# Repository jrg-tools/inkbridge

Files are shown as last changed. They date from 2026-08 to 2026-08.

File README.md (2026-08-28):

# inkbridge

A minimal, always-on **Home Assistant script launcher** on an e-ink display. Two mechanical buttons, sub-second feedback, runs for ages on almost no power.

```
┌──────────────────────────────┐
│                           (》)│
│                                │
│   ┌────────┐    ┌────────┐   │
│   │  bulb  │    │  wifi  │   │
│   │ Sleep  │    │Transfer│   │
│   └────────┘    └────────┘   │
│                                │
│ ──────────────────────────── │
│  A                      ▲ ▼  │
│                    "Sleep"    │
└──────────────────────────────┘
```

- A 2-column grid of icon-only buttons — each one a script configured in Home Assistant (lights, scenes, "goodnight" routines, whatever you script). Press it, it runs, done.
- Configure everything — WiFi networks (with automatic fallback), Home Assistant host/token, the script buttons and their icons, hotspot credentials, language, even the device's font — from a web UI the device serves itself.
- Multiple saved WiFi networks: tried in priority order until one connects, so it isn't stuck if you move it between locations.
- Idle **light sleep** after 5 minutes on any screen except while the config web UI is being used, waking instantly on either button. The header shows a small status icon (moon = about to nap, lightning = USB connected) that stays in sync even without touching a button.

Architecture follows [CrossPoint Reader](https://github.com/crosspoint-reader/crosspoint-reader): HAL singletons, an Android-style Activity stack for screens, a persisted settings singleton, an API-first web server, and — for the icon set — the same idea of rasterizing stock [Lucide](https://lucide.dev) icons to 1-bit bitmaps rather than hand-drawing vector shapes.

## Hardware

| Part | Details |
|---|---|
| MCU | Seeed Studio XIAO ESP32-S3 |
| Display | Waveshare 2.13" e-Paper HAT V4 (250x122, SPI) |
| Input | 2x Cherry MX switches (A/B) |
| Power | USB-C, EEMB 603449 LiPo (3.7V, 1100mAh) |

### Wiring

| HAT pin | XIAO pin | GPIO | Purpose |
|---|---|---:|---|
| VCC | 3V3 | — | Power |
| GND | GND | — | Ground |
| DIN | D10 | 9 | SPI MOSI |
| CLK | D8 | 7 | SPI clock |
| CS | D1 | 2 | Chip select |
| DC | D2 | 3 | Data/Command |
| RST | D3 | 4 | Reset |
| BUSY | D4 | 5 | Busy status |
| Button A | D6 | 43 | to GND (internal pull-up) |
| Button B | D7 | 44 | to GND (internal pull-up) |

### Power

- **Idle light sleep**: after 5 minutes untouched, the device drops into light sleep (`esp_light_sleep_start`) and wakes instantly on either button press. Skipped while the config web server is running (AP setup or a connected WiFi session), so it never naps mid-configuration.
- **No deep sleep**: true deep sleep wakeup (`ext0`/`ext1`) needs RTC-capable GPIOs (0–21 on the S3); the buttons are wired to GPIO43/44 (the UART pins), which aren't RTC pins. Light sleep's GPIO wakeup works on any digital pin instead, and has the added benefit of preserving all RAM state across the nap.
- **Rough battery life**: active draw is tens of mA; light sleep drops that to roughly 0.25–1 mA. At typical "check it a dozen-ish times a day" usage, that's on the order of 2–3 weeks per charge; left almost untouched, more like a month or two. Frequent short interactions cost more than you'd expect, since each one keeps it awake for the full 5-minute idle window afterward, not just the interaction itself.
- **Charging**: the XIAO's onboard charge management fast-charges at a fixed 100mA regardless of what the USB-C source can supply. For the 1100mAh cell here, that's roughly **11–14 hours** empty to full.
- No software-readable charging-status or battery-voltage pin exists on stock XIAO ESP32-S3 wiring — the header's lightning-bolt icon reflects "USB host connected" (native-USB frame detection), not literal charge state, and won't fire for a dumb USB-C power brick with no data lines.

## Using the device

Boot goes straight to the main menu — no radio starts until you pick something:

- **Script buttons**: each one configured in the web UI (label, HA script ID, icon) shows up as an icon-only square. Pressing it joins WiFi (trying each saved network in order), calls `script.turn_on` for that script's entity, and returns to the menu — a spinner is the only feedback while it works, and the footer shows its name while it's selected.
- **Transfer**: opens WiFi/hotspot connectivity —
  - *Setup hotspot* opens the access point `inkbridge-setup`. Join it, then open `http://inkbridge.local` (or `http://192.168.4.1`) to configure WiFi networks, Home Assistant host/token, scripts, hotspot, language, and font. Saving restarts the device.
  - *Connect WiFi* joins a saved network (again trying each until one connects) and starts the same config web server on your LAN — the screen then shows a QR code plus the mDNS name and IP to reach it from a browser. It does nothing else; no on-device entity control.

Button language (everywhere):

| Gesture | Action |
|---|---|
| A short | next row (wraps) |
| A long | previous row (wraps) |
| B short | select / run |
| B long | back |

The footer always shows a bold **A** (bottom-left, the action button) and up/down chevrons (bottom-right, the move button); on the main menu it also centers the currently selected item's name.

## Repository layout

```
lib/hal/                    Hardware abstraction (reusable, app-agnostic)
  HalDisplay                  GxEPD2 wrapper; FULL/FAST/region refresh, ghosting cadence
  HalGPIO                      Debounced buttons, short/long-press events, sleep-wakeup arming
scripts/
  gen_icons.py                 Rasterizes stock Lucide SVGs into 1-bit icon bitmaps
src/
  main.cpp                     Globals + setup()/loop(); idle-sleep + header status-icon polling
  InkBridgeSettings             Persisted settings singleton (NVS), SETTINGS macro
  Version.h                     Firmware version string
  IdleSleep.h                   Shared idle-timeout/warning-window constants and clock
  activities/                   One screen = one Activity
    Activity, ActivityManager     Lifecycle + deferred screen stack
    UiListActivity                 Reusable scrolling-list base
    menu/                           MainMenuActivity — the 2-column script/Transfer grid
    transfer/ network/ scripts/     Transfer menu, WiFi/hotspot screens, script-run screen
  components/                   UITheme (fonts/metrics), Icons + icons/IconBitmaps.h,
                                  UiChrome (header/footer/rows), QrCode (QR rendering)
  homeassistant/                 HA REST client — runs a script via script.turn_on
  network/                       ConfigWebServer (JSON API + static SvelteKit UI),
                                  WifiConnector (multi-network fallback)
  i18n/                          I18n singleton + EN/ES string table
web/                          SvelteKit config UI (TypeScript, pnpm, adapter-static, @lucide/svelte icon picker)
nix/                          Dev environment (flake)
data/                         Staged web build, flashed to LittleFS (generated)
```

## Development

### Environment

Everything is provided by the Nix dev shell (PlatformIO, Node 24, pnpm, clang-format):

```sh
nix develop ./nix
```

First entry bootstraps a `.venv` with PlatformIO Core automatically. Works on Linux (FHS env) and macOS. Without Nix you need: PlatformIO Core, Node.js >= 24, pnpm.

### Quick commands (inside the shell)

| Command | What it does |
|---|---|
| `build-ui` | Build the SvelteKit UI and stage it into `data/` |
| `flash-ui` | `build-ui` + flash the LittleFS partition |
| `flash` | Flash the firmware |
| `flash-monitor` | Flash the firmware + attach the serial monitor |
| `flash-all` | UI + filesystem + firmware + monitor (full deploy) |

First flash on a new board: `flash-all`. Day-to-day firmware work: `flash-monitor`. UI-only change: `flash-ui`.

### Working on the web UI

```sh
cd web
pnpm dev
```

`/api/*` calls are proxied to a real device — defaults to `inkbridge.local`, override with `INKBRIDGE_HOST=192.168.4.1 pnpm dev`. Put the device in Setup mode (or on your LAN) so the API is reachable.

`pnpm check` type-checks the app; `pnpm build` produces the static site; `pnpm deploy` does both and stages the result into `../data` (equivalent to the `build-ui` shell command above).

### Regenerating icons

Device icons are real [Lucide](https://lucide.dev) glyphs rasterized to 1-bit bitmaps (`src/components/icons/IconBitmaps.h`) — no hand-drawn vector shapes, no SVG rendering on-device. To add or change one, edit the `ICONS` list in `scripts/gen_icons.py` (path/circle/rect data, easiest lifted from `@lucide/svelte`'s source under `web/node_modules`) and rerun:

```sh
python3 scripts/gen_icons.py
```

Requires ImageMagick (`magick`) on `PATH` for SVG rasterization. Writes straight back into `src/components/icons/IconBitmaps.h` — don't hand-edit that file. If the icon is meant to be selectable from a script button, also add it to `ICON_OPTIONS` in `web/src/routes/+page.svelte` and to `Icons::byKey()` in `src/components/Icons.h`.

### Web API

The device is API-first; the UI is a static SvelteKit build served from LittleFS. CORS is enabled.

| Endpoint | Method | Description |
|---|---|---|
| `/api/status` | GET | `{version, ip, mode, rssi, freeHeap, uptime}` |
| `/api/settings` | GET | Current settings (secrets omitted; WiFi networks return SSID only) |
| `/api/settings` | POST | JSON body; applies + persists. Secrets/passwords only overwritten when present — matched by SSID for WiFi networks, so leaving a password blank keeps the stored one |
| `/api/restart` | POST | Reboot the device |

Settings are grouped as `transfer` (`wifiNetworks: [{ssid, password}]`, `haHost`, `haPort`, `haToken`, `haScripts: [{label, id, icon}]`) and `settings` (`language`, `fontFamily`, `apSsid`, `apPassword`).

### Conventions

- C++20, no exceptions in app code, 2-space indent, 120 columns
- `PascalCase` classes (one per file), `camelCase` methods/members, `UPPER_SNAKE_CASE` constants
- `lib/` is hardware-agnostic/reusable; `src/` is app logic
- Screens are Activities: implement `onEnter/onExit/loop/render`, request repaints with `requestUpdate()`; never transition mid-`loop()` — ask `activityManager`
- e-ink discipline: FAST (partial) refresh by default, full refresh every 15 frames to clear ghosting; use `refreshRegion()` when only a small area changed

## Roadmap

- [x] M0 — display, buttons, menu
- [x] M1 — WiFi (multi-network fallback) + Home Assistant
- [x] M2 — script launcher + web config + idle sleep
- [ ] M3 — shopping list (microSD)
- [ ] M4 — OTA updates

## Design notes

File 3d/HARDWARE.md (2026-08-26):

# Filament

| Characteristic | Specification |
|---|---|
| **Material** | PLA |
| **Color** | White |
| **Diameter** | 1.75 mm |
| **Diameter tolerance** | ±0.02 mm |
| **Net weight** | 1 kg / 2.2 lb |
| **Density** | 1.20 g/cm³ |
| **Tensile strength (X-Y)** | ≥ 50 MPa |
| **Elongation at break** | 11.2% |
| **Bending strength** | 91 MPa |
| **Bending modulus** | 1913 MPa |
| **Impact strength** | 5.4 kJ/m² |
| **Heat deflection temperature** | 53°C @ 0.45 MPa |
| **Rockwell hardness** | 88 |
| **Nozzle temperature** | 190–230°C |
| **Recommended nozzle temperature** | ~205°C |
| **Bed temperature** | 50–65°C |
| **Recommended print speed** | 30–70 mm/s |
| **Part cooling fan** | 100% |
| **Drying temperature** | 55 ± 5°C |
| **Storage humidity** | ≤20% RH |
| **Filament length** | ~330–335 m/kg |

## Bambu A1 Starting Profile

- **Filament type:** Generic PLA
- **Nozzle:** 205°C
- **Bed:** 55–60°C
- **Part cooling:** 100%
- **Print speed:** 30–70 mm/s for conservative printing
- **Drying:** 55°C for ~6 h if moisture is suspected

## Notes

- The **±0.02 mm** specification refers to filament diameter tolerance, not printed-part dimensional accuracy.
- Compatible with standard **1.75 mm FDM/FFF 3D printers**.
- Suitable for general-purpose PLA printing.

# Components

## EEMB 3.7V 1100mAh LiPo Battery — 603449

| Characteristic | Specification |
| --- | --- |
| **Manufacturer** | EEMB |
| **Battery type** | Lithium-Polymer (LiPo) |
| **Nominal voltage** | 3.7 V |
| **Capacity** | 1100 mAh |
| **Energy** | ~4.07 Wh |
| **Model / Size** | 603449 |
| **Dimensions** | 34.5 × 51 × 6.3 mm |
| **Connector** | JST-PHR-02 |
| **Connector pitch** | 2.0 mm |
| **Wires** | Red (+) / Black (−) |
| **Protection** | Built-in PCM |
| **Protection features** | Overcharge, over-discharge, over-current, short circuit |
| **Cycle life** | >500 cycles |
| **Certifications** | UL, IEC 62133-2 |
| **Transportation** | UN38.3 compliant |
| **Recommended storage charge** | 40–60% |
| **Storage voltage** | 3.7–4.0 V |
| **Recommended recharge interval** | Every 3 months |
| **Maximum recommended storage temperature** | <25°C |
| **Recommended storage conditions** | Cool and dry place |

## 2.13" SPI E-Ink / E-Paper Display HAT

| Characteristic | Specification |
| --- | --- |
| **Display type** | Electronic Paper / E-Ink |
| **Display size** | 2.13" |
| **Display area** | 23.71 × 48.55 mm |
| **Resolution** | 250 × 122 pixels |
| **Aspect ratio** | ~2.05:1 |
| **Pixel / dot pitch** | 0.194 × 0.194 mm |
| **Shown colors** | Black & White |
| **Gray levels** | 2 |
| **Interface** | SPI |
| **Operating voltage** | 3.3 V / 5 V |
| **Partial refresh time** | ~0.3 s |
| **Full refresh time** | ~2 s |
| **Refresh power** | ~26.4 mW (typ.) |
| **Standby power** | <0.017 mW |
| **Viewing angle** | >170° |
| **Module dimensions** | ~65 × 30 mm |
| **Compatible platforms** | Raspberry Pi, Arduino and other SPI-compatible MCUs |

## Seeed Studio XIAO ESP32-S3 Sense — Without Camera

| Characteristic | Specification |
| --- | --- |
| **MCU** | ESP32-S3 |
| **CPU architecture** | 32-bit Xtensa |
| **CPU cores** | Dual-core |
| **Maximum frequency** | 240 MHz |
| **Wi-Fi** | 2.4 GHz |
| **Bluetooth** | BLE 5.0 |
| **PSRAM** | 8 MB |
| **Flash** | 8 MB |
| **Digital microphone** | Yes |
| **Camera** | **Removed / not used** |
| **SD card support** | Yes |
| **Maximum SD card capacity** | 32 GB |
| **SD card filesystem** | FAT |
| **Battery charging** | Yes |
| **Antenna connector** | U.FL |
| **Wireless range** | >100 m with external U.FL antenna (manufacturer claim) |
| **Board dimensions** | 21 × 17.5 mm |
| **Development platforms** | Arduino, MicroPython |
| **Form factor** | Seeed Studio XIAO |

## Cherry MX2A Silent Blue — Mechanical Keyboard Switch

| Characteristic | Specification |
| --- | --- |
| **Brand** | 遊舎工房 |
| **Manufacturer** | 遊舎工房 |
| **Switch model** | Cherry MX2A Silent Blue |
| **Switch type** | Tactile |
| **Color / Axis** | Blue |
| **Actuation type** | Clicky |
| **Pins** | 5-pin |
| **Compatibility** | Cherry MX |
| **Total travel** | 4.0 mm |
| **Working / actuation travel** | 2.2 mm |
| **Operating force** | 50 cN |
| **Package quantity** | 35 switches |
| **Package dimensions** | 14.4 × 10.6 × 2.4 cm |
| **Package weight** | 100 g |
| **Factory lubrication** | No |

## YMDK Kailh Hot-Swappable PCB Socket — CPG151101S11

| Characteristic | Specification |
| --- | --- |
| **Brand** | YMDK / Kailh |
| **Model** | CPG151101S11 |
| **Component type** | Mechanical keyboard hot-swap socket  |
| **Package quantity** | 50 sockets |
| **Rated voltage** | 12 V AC/DC max |
| **Minimum rated voltage** | 2 V AC min |
| **Rated current** | 10 mA AC/DC max |
| **Minimum rated current** | 10 μA DC |
| **Contact resistance** | ≤200 mΩ |
| **Insulation resistance** | ≥100 mΩ @ 100 V DC |
| **Withstanding voltage** | AC 100 V, 50–60 Hz |
| **Insertion / motivational force** | ≤6.6 lbf / 3.0 kgf |
| **Operating life** | 100 cycles |
| **Switch compatibility** | Kailh / MX-style mechanical switches |
| **Application** | Mechanical keyboard / keypad / HMI |

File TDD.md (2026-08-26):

# TDD — eink-remote: Home Assistant Controller on ESP32-S3

## 1. Overview

**eink-remote** is a minimal, self-contained Home Assistant remote controller built on an ESP32-S3 with a 2.13" e-ink display, 2 mechanical buttons, microSD storage, and a microphone for voice input.

The device acts as a **local physical interface** to Home Assistant:
- Control lights, switches, and other entities
- Display live state from Home Assistant
- Maintain a shopping list
- Receive firmware updates over-the-air
- Configure settings via a local web server

It is **not** a general-purpose IoT platform. It solves one problem very well: being a fast, low-power, always-available physical remote control.

---

## 2. Hardware

**MCU:** Seeed Studio XIAO ESP32-S3
- 14 GPIO pins total
- Wi-Fi + BLE capable
- USB-C power/programming

**Display:** Waveshare 2.13" e-Paper HAT V4
- 250x122 pixel resolution
- SPI interface (6 GPIO pins)
- Low power (only draws current during refresh)

**Input:** 2x Cherry MX mechanical switches (hotswap PCB)
- GPIO interrupt-based (2 GPIO pins)
- Physical feedback (important for UX)
- Debounced in hardware (20ms)
- Short-press / long-press / double-press patterns to compensate for fewer keys

**Storage:** microSD card (SPI mode)
- Shares SPI bus with display (separate CS pin → 1 extra GPIO)
- Stores shopping list, logs, audio clips, config backups

**Microphone:** The XIAO ESP32-S3 (base version) has **no** built-in mic
- The XIAO ESP32-S3 **Sense** variant includes a PDM digital microphone + microSD slot (recommended — solves both needs with zero wiring)
- Otherwise: external I2S MEMS mic (e.g. INMP441/SPH0645, 3 GPIO pins)

**Power:** USB-C (for now; future: battery + low-power deep sleep)

#### Pin Connection

| # | HAT pin (silkscreen order) | Wire color (typical Waveshare cable) | XIAO label | XIAO GPIO | Purpose |
| - | --- | --- | --- | ---: | --- |
| 1 | VCC | grey/red | `3V3` | — | Power (3.3 V) |
| 2 | GND | brown/black | `GND` | — | Ground |
| 3 | DIN | blue | `D10` | 9 | SPI MOSI (data in) |
| 4 | CLK | yellow | `D8` | 7 | SPI clock |
| 5 | CS | orange | `D1` | 2 | Chip select |
| 6 | DC | green | `D2` | 3 | Data/Command |
| 7 | RST | white | `D3` | 4 | Reset |
| 8 | BUSY | purple | `D4` | 5 | Busy status |

---

## 3. Goals

### Primary

1. Build a working Home Assistant remote controller
2. Display live HA entity state on e-ink
3. Control HA lights/switches via 2 physical buttons
4. Navigate between remote, dashboard, and shopping list screens
5. Persist configuration (Wi-Fi, HA host, token) across reboot
6. Support Over-The-Air firmware updates
7. Make the UI responsive (button press → display update in <1 second)
8. Run on minimal power (e-ink refresh only when state changes)

### Secondary

- Sync shopping list with HA (optional YAML helper)
- BLE presence detection (future)
- Battery + deep sleep (future)
- Scheduled automations (future)

---

## 4. Non-Goals

- **Not** a general IoT platform (unlike the original TDD)
- **Not** replacing Home Assistant (HA remains the brain)
- **Not** building an e-reader
- **Not** supporting complex automations on-device
- **Not** providing a full dashboard (limited display size)
- **Not** cloud connectivity (local network only)

---

## 5. High-Level Architecture

```mermaid
graph TB
    HA[Home Assistant<br/>on local network]
    
    WiFi[Wi-Fi]
    
    subgraph "eink-remote"
        App["Application<br/>Event Loop"]
        Display["Display<br/>Renderer"]
        Buttons["Button<br/>Handler"]
        Storage["Storage<br/>NVS + microSD"]
        HAClient["HA Client<br/>REST/WebSocket"]
        Web["Web Config<br/>Server"]
        ShoppingList["Shopping List<br/>Manager"]
    end
    
    Disp["e-Ink Display<br/>2.13in"]
    Btn["2x Cherry MX<br/>Switches"]
    Mic["Microphone<br/>PDM/I2S"]
    SD["microSD Card<br/>SPI"]
    
    HA -->|REST/WS| WiFi
    WiFi -->|Wi-Fi| HAClient
    
    Buttons -->|Button events| App
    HAClient -->|State updates| App
    App -->|Render command| Display
    Display -->|Pixel data| Disp
    
    Web -->|Config form| App
    ShoppingList -->|Add/Remove| Storage
    App -->|Read/Write| Storage
    
    HAClient -->|Read| Storage
    Web -->|Read/Write| Storage
    Mic -->|Audio samples| App
    Storage -->|FS| SD
```

---

## 6. Technology Stack

| Component | Technology | Justification |
|---|---|---|
| MCU | ESP32-S3 | Wi-Fi, plenty of GPIO, Waveshare support |
| Firmware | ESP-IDF | C++17, FreeRTOS, battle-tested |
| Build | PlatformIO | Cross-platform, simple CLI |
| Display Driver | ESP-IDF SPI + custom | Waveshare library (or custom) |
| Button Handler | GPIO interrupts + FreeRTOS timers | Low-power, responsive |
| HA Integration | HTTP REST (primary), WebSocket (future) | Simple, no dependencies |
| Config Storage | NVS (secrets) + microSD (shopping list, logs, audio) | Flash-backed secrets, removable bulk storage |
| Microphone | PDM (Sense variant) or I2S MEMS mic | Built-in on XIAO Sense, minimal wiring |
| Web Server | esp_http_server (built-in) | Minimal overhead |
| Language | C++17 | Modern abstractions without overhead |

---

## 7. Repository Structure

```
eink-remote/
├── platformio.ini                 (project config)
├── README.md
├── LICENSE
│
├── src/
│   ├── main.cpp                   (entry point + event loop)
│   │
│   ├── config/
│   │   ├── config.h               (Config struct, persistence)
│   │   ├── config.cpp
│   │   └── defaults.h
│   │
│   ├── display/
│   │   ├── display.h              (abstract display interface)
│   │   ├── display.cpp            (e-ink driver + SPI)
│   │   │
│   │   └── ui/
│   │       ├── screens.h          (Screen enum + rendering)
│   │       ├── remote.cpp         (HA entity control UI)
│   │       ├── dashboard.cpp      (state display UI)
│   │       └── shopping.cpp       (shopping list UI)
│   │
│   ├── input/
│   │   ├── buttons.h              (Button class)
│   │   └── buttons.cpp            (GPIO + debounce)
│   │
│   ├── network/
│   │   ├── wifi.h / .cpp
│   │   ├── mdns.h / .cpp
│   │   └── ntp.h / .cpp           (optional: time sync)
│   │
│   ├── homeassistant/
│   │   ├── client.h               (HA REST API wrapper)
│   │   ├── client.cpp
│   │   └── entities.h             (entity definitions)
│   │
│   ├── web/
│   │   ├── server.h               (HTTP server)
│   │   ├── server.cpp
│   │   └── assets/
│   │       └── index.html         (config UI)
│   │
│   └── storage/
│       ├── shopping_list.h        (in-memory + microSD)
│       └── shopping_list.cpp
│
├── test/
│   ├── test_config.cpp
│   ├── test_buttons.cpp
│   └── test_shopping_list.cpp
│
└── docs/
    ├── WIRING.md                  (pinout reference)
    ├── BUTTON_PATTERNS.md         (navigation guide)
    └── API.md                     (HTTP endpoints)
```

---

## 8. Core Components

### 8.1 Display (Most Complex)

**Problem:** e-ink is slow (~1-2 seconds refresh). Must be smart about updates.

**Solution:**
- Keep a **frame buffer in RAM**
- Only refresh display on **actual state changes**
- Use **partial refresh** when possible (Waveshare supports it)
- Clear screen only when necessary

```cpp
class Display {
public:
    void init();
    void draw_text(int x, int y, const char* text);
    void draw_box(int x, int y, int w, int h);
    void clear();
    void refresh();           // Sends buffer to device
    void refresh_partial();   // Faster, only changed region
};

class RemoteScreen {
public:
    void render(const std::vector<Entity>& entities, int selected);
    bool is_dirty();
    void mark_clean();
};
```

**Rendering Strategy:**
```
Main Loop (every 100ms)
    ↓
Check HA state changed?
    ↓ YES
Update frame buffer
    ↓
Call display.refresh()
    ↓
e-ink controller
    ↓
Physical display updates
```

---

### 8.2 Button Handler

**Design:** Interrupt-driven + debounce

```cpp
enum class Button { A, B };
enum class ButtonState { PRESSED, RELEASED };
enum class ButtonEvent { SHORT_PRESS, LONG_PRESS, DOUBLE_PRESS };

class Buttons {
public:
    void init();
    void on_event(std::function<void(Button, ButtonEvent)> cb);
    ButtonState get_state(Button btn);
};
```

**GPIO Assignment:**
```
Button A → GPIO 21 (D0)
Button B → GPIO 6  (D5)
```

**Debounce:** 20ms timer-based (hardware debounce, very reliable)

**With only 2 keys, gestures carry the navigation:**
```
A short:  scroll down / next item
A long:   next screen
A double: scroll up
B short:  select / toggle
B long:   menu / back
B double: voice input (push-to-talk via mic)
```

---

### 8.3 Navigation & Screens

**Screen Flow:**

```mermaid
stateDiagram-v2
    [*] --> Remote
    
    Remote --> Dashboard: Long-press A (next)
    Dashboard --> Shopping: Long-press A (next)
    Shopping --> Remote: Long-press A (next)
    
    Remote --> Menu: Long-press B
    Dashboard --> Menu: Long-press B
    Shopping --> Menu: Long-press B
    
    Menu --> Remote: Long-press B (back)
```

**Button Mapping (Navigation Pattern):**
```
A short:  scroll down
A double: scroll up
A long:   next screen (cycles Remote → Dashboard → Shopping)
B short:  select / toggle
B long:   menu / back
B double: voice input
```

---

### 8.4 Home Assistant Client

**Minimal REST API approach:**

```cpp
class HomeAssistant {
public:
    bool connect();
    bool is_connected();
    
    // Core operations
    std::vector<Entity> get_entities();
    bool call_service(const Entity& entity, bool state);
    
    void disconnect();
};
```

**HTTP Endpoints Used:**
```
GET  /api/states                          (fetch all entities)
POST /api/services/light/turn_on          (control)
POST /api/services/switch/turn_on
POST /api/services/switch/turn_off
```

**Future:** WebSocket for real-time updates (less polling)

---

### 8.5 Configuration & Storage

**NVS (for secrets):**
```cpp
struct Config {
    std::string device_name;      // "eink-remote"
    std::string ssid;             // WiFi SSID
    std::string password;         // WiFi password (encrypted)
    std::string ha_host;          // "homeassistant.local"
    std::string ha_token;         // Bearer token
    int ha_port = 8123;
    
    void load();
    void save();
};
```

**microSD (for shopping list, logs, audio clips):**
```json
{
  "items": ["Milk", "Eggs", "Bread"],
  "timestamp": 1692547200
}
```

---

### 8.6 Web Configuration Server

**Simple HTML form served on boot:**

```
http://eink-remote.local/

[Config Form]
- Device Name
- WiFi SSID
- WiFi Password
- HA Host
- HA Token

[Save] → POST /api/config → Restart device
```

**Endpoints:**
```
GET  /                 (serve index.html)
GET  /api/status       (device info)
POST /api/config       (save config)
GET  /api/config       (get current config, no secrets)
POST /api/restart      (reboot device)
```

---

## 9. Screen Designs

### Remote Control Screen

```
┌─────────────────────┐
│ REMOTE CONTROL      │
├─────────────────────┤
│                     │
│  [Light: Kitchen]   │
│  Status: ON  ◀─────│← Selected (highlighted)
│  Brightness: 100%   │
│                     │
│  [Light: Living]    │
│  Status: OFF        │
│                     │
├─────────────────────┤
│ ▲▼ A: scroll/screen  │
│ B: select/menu       │
└─────────────────────┘
```

### Dashboard Screen

```
┌─────────────────────┐
│ DASHBOARD           │
├─────────────────────┤
│                     │
│ Temperature:  22°C  │
│ Humidity:     55%   │
│                     │
│ Light Kitchen: ON   │
│ Light Living: OFF   │
│ Fan: ON             │
│                     │
├─────────────────────┤
│ < Previous  > Next  │
│ Status: Connected   │
└─────────────────────┘
```

### Shopping List Screen

```
┌─────────────────────┐
│ SHOPPING LIST       │
├─────────────────────┤
│                     │
│  ✓ Milk             │
│  ✓ Eggs             │
│ ▶ Bread      ◀──── │ Selected
│    Butter          │
│    Cheese          │
│                     │
├─────────────────────┤
│ A: scroll  B: sel   │
│ A-long: next screen │
└─────────────────────┘
```

---

## 10. Main Event Loop

```cpp
extern "C" void app_main()
{
    // 1. Initialize
    Config config;
    config.load();
    
    Display display;
    display.init();
    
    Buttons buttons;
    buttons.init();
    buttons.on_event(handle_button_event);
    
    WiFi wifi;
    wifi.connect(config.ssid, config.password);
    
    HomeAssistant ha;
    ha.connect(config.ha_host, config.ha_token);
    
    WebServer web;
    web.start();
    
    ShoppingList shopping;
    shopping.load();
    
    // 2. Main loop
    TickType_t last_sync = 0;
    Screen current_screen = Screen::REMOTE;
    
    while (true) {
        // Periodically sync HA state (every 5 seconds)
        if (xTaskGetTickCount() - last_sync > pdMS_TO_TICKS(5000)) {
            auto entities = ha.get_entities();
            update_state(entities);
            last_sync = xTaskGetTickCount();
        }
        
        // Re-render if dirty
        if (display_needs_refresh()) {
            render_screen(current_screen);
            display.refresh();
        }
        
        vTaskDelay(pdMS_TO_TICKS(100));
    }
}

void handle_button_event(Button btn, ButtonEvent evt)
{
    if (btn == Button::A) {
        switch (evt) {
            case ButtonEvent::SHORT_PRESS:  scroll_down(); break;
            case ButtonEvent::DOUBLE_PRESS: scroll_up(); break;
            case ButtonEvent::LONG_PRESS:   next_screen(); break;
        }
    } else { // Button::B
        switch (evt) {
            case ButtonEvent::SHORT_PRESS:  select_current_item(); break;
            case ButtonEvent::LONG_PRESS:   open_menu(); break;
            case ButtonEvent::DOUBLE_PRESS: start_voice_input(); break;
        }
    }
    
    mark_display_dirty();
}
```

---

## 11. Error Handling & Resilience

**Key Principle:** Device remains functional even if Home Assistant is offline.

```
┌─────────────────────────┐
│ HA Connection Lost      │
├─────────────────────────┤
│ Device continues running│
│ Display shows "HA: ???" │
│ Buttons still work      │
│ Retry connection every  │
│ 30 seconds              │
│                         │
│ When HA returns:        │
│ - Sync state           │
│ - Refresh display      │
└─────────────────────────┘
```

**WiFi Loss:**
- Automatic reconnection (exponential backoff)
- Display shows "WiFi: Searching..."
- All features offline until reconnected

**Display Error:**
- Log to serial
- Continue running (no panic)
- Retry initialization

---

## 12. Persistence & Boot Sequence

```mermaid
sequenceDiagram
    participant Boot
    participant NVS
    participant WiFi
    participant HA
    participant Display
    
    Boot->>NVS: Load config
    alt Config found
        NVS-->>Boot: Config
    else First boot
        NVS-->>Boot: Defaults
    end
    
    Boot->>WiFi: Connect with SSID/pass
    alt Connected
        WiFi-->>Boot: OK
        Boot->>HA: Authenticate with token
        HA-->>Boot: Connected
    else Not connected
        WiFi-->>Boot: Fail
        Boot->>Display: Show WiFi error
    end
    
    Boot->>Display: Render initial screen
    Display-->>Boot: Ready
    
    Boot->>Boot: Enter main loop
```

---

## 13. Testing Strategy

### Unit Tests (native, no hardware)

```cpp
// test/test_config.cpp
TEST(Config, LoadFromNVS) {
    Config c;
    c.load();
    EXPECT_EQ(c.device_name, "eink-remote");
}

// test/test_shopping_list.cpp
TEST(ShoppingList, AddItem) {
    ShoppingList list;
    list.add("Milk");
    EXPECT_EQ(list.get_items().size(), 1);
}
```

Run with:
```bash
pio test
```

### Integration Tests (on hardware)

Manual steps:
1. Boot device → display shows initial screen
2. Press buttons A/B (short, long, double) → confirm all gestures respond
3. Connect to HA → verify state displayed
4. Toggle a light in HA → verify displayed on device
5. Press button to control light → verify HA state changes
6. Disconnect WiFi → verify device continues working
7. Reconnect WiFi → verify state re-syncs

### Hardware Tests

- e-ink refresh speed (<2 seconds full, <500ms partial)
- Button debounce accuracy (no ghost presses)
- WiFi reconnection (should succeed within 10 seconds)
- Memory stability (run for 1 hour, verify no crashes)

---

## 14. Development Workflow

### Local Development

```bash
# Clone repo
git clone https://github.com/you/eink-remote.git
cd eink-remote

# Install dependencies
pip install platformio

# Build
pio run

# Connect XIAO via USB, flash
pio run --target upload

# Monitor serial output
pio device monitor

# Run tests (on host)
pio test
```

### Debugging

```bash
# Serial monitor with timestamps
pio device monitor --raw

# From another terminal, push config:
curl -X POST http://eink-remote.local/api/config \
  -d '{"ssid":"MyWiFi","password":"pass"}'
```

### Git Workflow

```
main (stable)
  ↓
feature/shopping-list (develop)
  ↓
Test locally on hardware
  ↓
PR → merge to main
  ↓
Tag release (v0.1.0)
  ↓
Create firmware artifact
```

---

## 15. Milestones

### M0: Hello Display (1-2 days)

**Goal:** Display renders, buttons detect presses

- ✅ Display initialization + text rendering
- ✅ Button interrupts + debounce
- ✅ Serial logging working
- ✅ Main loop running

**Definition of Done:**
```
[Device boots]
Display shows: "eink-remote ready"
Press Button A → Serial: "Button A PRESSED"
```

---

### M1: WiFi + Home Assistant (2-3 days)

**Goal:** Connect to HA, read entity state

- ✅ Wi-Fi connection (hardcoded SSID/pass for now)
- ✅ mDNS hostname
- ✅ HA client (HTTP REST)
- ✅ Fetch entity list from HA
- ✅ Display entity state

**Definition of Done:**
```
Connect to WiFi
Navigate to http://eink-remote.local
Display shows: "Connected to HA"
Display shows 3 entity states
```

---

### M2: Remote Control (2-3 days)

**Goal:** Control entities from device

- ✅ Button navigation between screens
- ✅ Select entity (highlight on display)
- ✅ Toggle light/switch via button press
- ✅ Display reflects change immediately
- ✅ Web config server (SSID, password, HA token)

**Definition of Done:**
```
Navigate to Remote screen (long-press A)
Select a light
Press Button B to toggle
Light turns on/off in HA AND on display
Visit http://eink-remote.local
Configure WiFi + HA
Reboot → device remembers config
```

---

### M3: Shopping List (1-2 days)

**Goal:** Persistent shopping list on device

- ✅ Shopping list screen (separate from remote)
- ✅ Add item (via button + text input)
- ✅ Delete item
- ✅ Save to microSD
- ✅ Load on boot

**Definition of Done:**
```
Navigate to Shopping screen (long-press A)
Add "Milk" → display updates
Reboot device
Shopping list persists
```

---

### M4: OTA + Final Polish (1-2 days)

**Goal:** Ship-ready firmware

- ✅ OTA update endpoint (`POST /api/ota`)
- ✅ Firmware validation
- ✅ Config migration (if schema changes)
- ✅ Error messages on display
- ✅ Documentation complete

**Definition of Done:**
```
All milestones working
Device handles errors gracefully
HA offline → display shows "HA: ???", still functional
WiFi loss → auto-reconnect
Device survives 1-hour stability test
```

---

## 16. Definition of Done for v0.1.0

Version `0.1.0` is complete when:

**Hardware**
- [ ] Both buttons respond to short/long/double presses
- [ ] e-ink display renders text and graphics
- [ ] No ghosting or spurious button presses
- [ ] Display refresh takes <2 seconds

**Network**
- [ ] Device connects to configured WiFi
- [ ] Automatically reconnects after WiFi loss
- [ ] Discoverable via mDNS (eink-remote.local)
- [ ] Survives Wi-Fi interruption for 30+ minutes

**Home Assistant**
- [ ] Authenticates with HA token
- [ ] Fetches entity state
- [ ] Controls lights/switches
- [ ] Displays state changes
- [ ] Survives HA being offline

**Configuration**
- [ ] Web server accessible at http://eink-remote.local
- [ ] Can configure WiFi, HA host, token
- [ ] Settings persist across reboot
- [ ] No secrets in logs or repositories

**UI/UX**
- [ ] Remote screen shows 3+ entities with toggle capability
- [ ] Dashboard screen displays state information
- [ ] Shopping list screen allows add/delete/save
- [ ] Button press → display update in <1 second
- [ ] Screen navigation smooth and responsive

**Reliability**
- [ ] Device survives hard reset without corruption
- [ ] No memory leaks over 1-hour runtime
- [ ] Graceful handling of HA unavailable
- [ ] Clear error messages on display

**Code Quality**
- [ ] No compiler warnings
- [ ] Unit tests for config, shopping list, display
- [ ] Clear comments for complex logic
- [ ] README + wiring guide complete

---

## 17. Future Enhancements (Post-v0.1)

| Feature | Effort | Value |
|---|---|---|
| WebSocket for real-time HA updates | Medium | High (less polling) |
| Battery + deep sleep | High | High (portability) |
| BLE presence detection | Medium | Medium |
| Local automations (if-this-then-that) | High | Low (HA is better at this) |
| Custom entity templates | Medium | Medium |
| Touchscreen (future hardware) | High | Medium |

---

## 18. Security Considerations

**Current Threats & Mitigations:**

| Threat | Impact | Mitigation |
|---|---|---|
| HA token exposed in logs | High | Redact token from serial output |
| WiFi password hardcoded | High | Store only in NVS, never in code |
| Unauthenticated config API | Medium | Require auth for destructive endpoints (future) |
| Network is untrusted | Low | Assume trusted LAN only for v0.1 |
| Firmware tampering | Low | Validate firmware signature before flash (future) |

**Never commit to git:**
```
src/config/secrets.h
.env
*.key
```

---

## 19. Design Principles

### 1. Local-First
Device works offline. HA is optional for remote control.

### 2. Simplicity
Single purpose: remote + dashboard. Resist feature creep.

### 3. Responsiveness
Button press → display update in <1 second (human perception threshold).

### 4. Power Efficiency
e-ink only refreshes on state change. No constant polling.

### 5. Robustness
WiFi down? HA down? Device still runs. Graceful degradation.

### 6. Debuggability
Clear serial logging. Easy to diagnose issues over USB.

---

## 20. Success Metrics

| Metric | Target | How to Measure |
|---|---|---|
| Button response time | <100ms | Press button, count to display update |
| HA sync latency | <5s | Toggle light, measure display update |
| WiFi reconnection | <30s | Disconnect WiFi, check logs |
| Memory usage | <50% heap | Check `free_heap` in diagnostics |
| Display uptime | >48 hours | Leave running, check logs |
| WiFi stability | 0 unexpected reboots | Monitor for 24 hours |

---

## 21. Risk Assessment

| Risk | Likelihood | Impact | Mitigation |
|---|---|---|---|
| e-ink driver bugs | High | High | Use Waveshare examples, extensive testing |
| WiFi disconnects | Medium | Medium | Robust reconnection + display feedback |
| HA API changes | Low | High | Version pin HA, monitor releases |
| Memory exhaustion | Low | High | Profile heap, limit buffer sizes |
| Button contact wear | Low | Medium | Use quality switches, firmware debounce |

---

## 22. Deployment Strategy

### Local Deployment

```bash
# Flash device over USB
pio run --target upload

# Or via OTA (future)
curl -F "file=@.pio/build/firmware.bin" \
  http://eink-remote.local/api/ota
```

### Release Process

```
Tag version: v0.1.0
    ↓
GitHub Actions builds firmware
    ↓
Artifact uploaded to Releases
    ↓
User downloads .bin file
    ↓
Flash via PlatformIO or web UI
```

---

## 23. Documentation Map

| Document | Purpose |
|---|---|
| README.md | Getting started |
| WIRING.md | Hardware pinout |
| BUTTON_PATTERNS.md | Navigation guide |
| API.md | HTTP endpoints |
| ARCHITECTURE.md | Design deep-dive |
| TROUBLESHOOTING.md | Common issues |

---

## 24. Estimated Timeline

| Phase | Duration | Owner |
|---|---|---|
| M0: Display + Buttons | 1-2 days | You |
| M1: WiFi + HA | 2-3 days | You |
| M2: Remote Control | 2-3 days | You |
| M3: Shopping List | 1-2 days | You |
| M4: OTA + Docs | 1-2 days | You |
| **Total** | **~7-12 days** | |

---

## 25. Final Vision

```
┌──────────────────────────────────────┐
│                                      │
│      eink-remote on your desk       │
│                                      │
│  [e-Ink Display]                    │
│  ┌────────────────────────┐         │
│  │ REMOTE CONTROL         │         │
│  │ Light: Kitchen ON  👈  │         │
│  │ Light: Living OFF      │         │
│  │ Fan: ON                │         │
│  └────────────────────────┘         │
│   ▲  ◄────►  ▼                      │
│   A         B                       │
│   │         │                       │
│   └─────────┘ (2 cherry switches)  │
│                                     │
│  ← Quick access to your home       │
│  ← Always on your nightstand       │
│  ← No phone needed for basics      │
│  ← Powered by Home Assistant       │
│                                     │
└──────────────────────────────────────┘
```

---

## Summary

This is a **focused, achievable project** with:
- Clear milestones (4 phases, ~2 weeks)
- Specific hardware constraints (GPIO budget: 6 display + 2 buttons + microSD CS + mic; XIAO Sense variant recommended)
- Pragmatic scope (remote + dashboard + shopping list, nothing more)
- Realistic error handling (HA offline, WiFi loss)
- Production-ready mindset (tests, docs, security)

Start with M0 (display + buttons), ship M2 (remote control) for real value, then add niceties.

Good luck! 🚀\

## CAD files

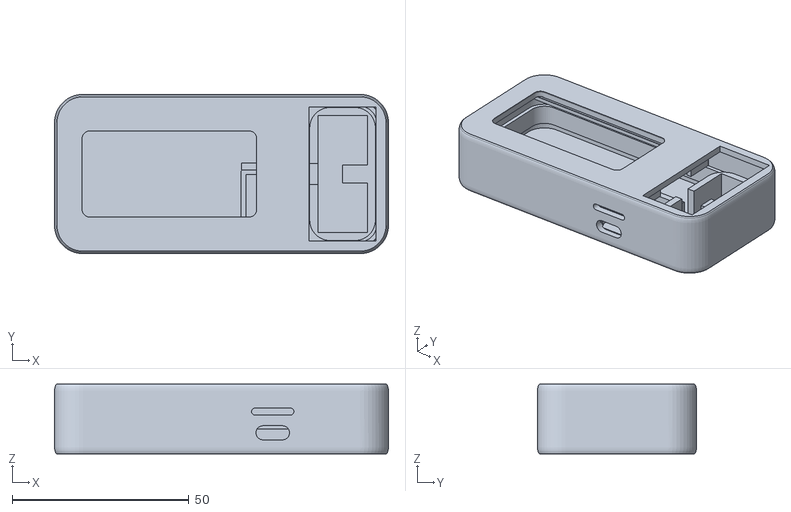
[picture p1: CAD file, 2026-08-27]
3d/case_assembled_preview.stl
94.5 x 45.0 x 19.8

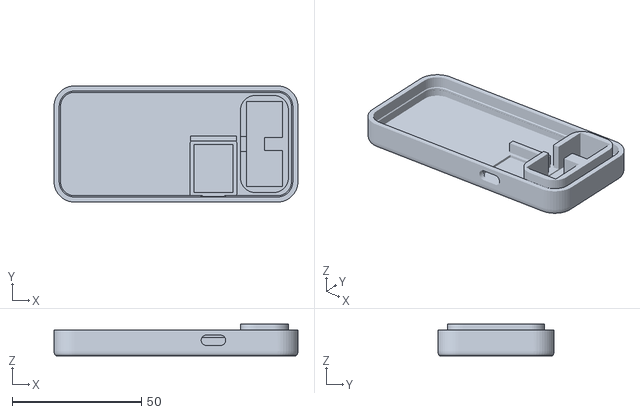
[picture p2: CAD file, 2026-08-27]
3d/case_bottom.stl
94.5 x 45.0 x 12.2

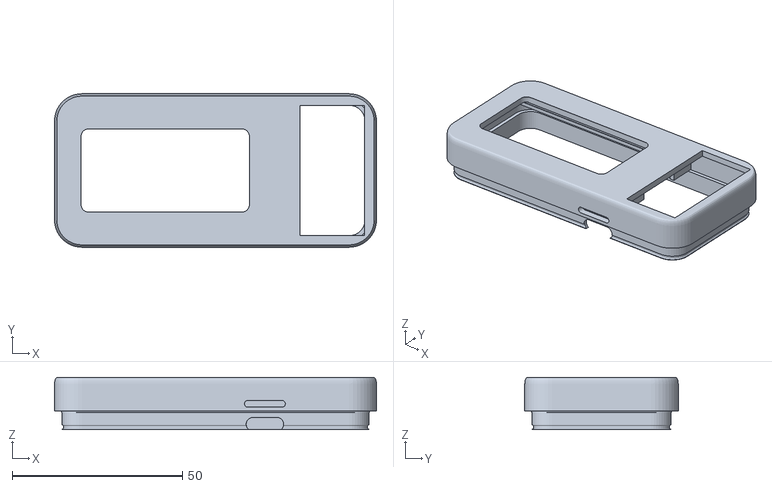
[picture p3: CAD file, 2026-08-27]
3d/case_top.stl
94.5 x 45.0 x 15.4

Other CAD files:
3d/case_preview.FCStd

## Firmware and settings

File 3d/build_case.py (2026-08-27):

#!/usr/bin/env python3
"""
build_case.py -- Parametric FreeCAD Part-API generator for a snap-fit
enclosure for a portable ESP32-S3 device (e-ink display + 2 mechanical
switches + LiPo battery), split into TWO printed parts (a bottom TRAY and
a top LID) joined by a continuous perimeter hook-and-lip snap, interrupted
at the USB-C port.

RUN IT
------
    freecadcmd build_case.py
or paste the whole file into FreeCAD's Python console, or run it as a Macro.
No manual GUI steps are required. Re-running is idempotent (it opens a
fresh in-memory document each time).

Outputs, written next to this script:
    case_bottom.stl            -- the tray, PRINT THIS (bed-ready: Z=0 is
                                   the floor's underside)
    case_top.stl                -- the lid, PRINT THIS (bed-ready: Z=0 is
                                   the skirt's free tip)
    case_assembled_preview.stl   -- both parts in their correct assembled
                                   position, for a visual fit-check in any
                                   STL viewer. NOT for printing -- it's a
                                   compound of the same two solids above,
                                   just positioned to show the mate. If
                                   you load case_bottom.stl and
                                   case_top.stl directly into a slicer and
                                   they look misaligned, that's this: each
                                   is intentionally zeroed to its own
                                   print-bed contact face, not to a shared
                                   assembly origin. Load this file instead
                                   to check the fit.
    case_preview.FCStd            -- both solids in one FreeCAD document
                                   (same assembled position), for
                                   inspection/editing in the GUI

To see the computed numbers behind every decision below, run:
    freecadcmd build_case.py --summary
which prints print_summary() and exits without exporting anything (fast,
for iterating on constants).

====================================================================
DESIGN OVERVIEW
====================================================================

LAYOUT: a single row, floor to floor: battery, then the MCU, then the
switch column, all sitting side by side in the plan view (not stacked in
Z) -- the battery and MCU zones share their dividing wall since they sit
flush against each other. The e-ink display is the only thing still
stacked in Z: it's adhesive-mounted above the battery+MCU row, spanning
both of their footprints, at DISPLAY_REST_Z (section 5). Only the display
trades case height for a smaller footprint now; the battery and MCU no
longer do.

SUPPORT: the MCU rests on a floor-level shelf pocket (shelf_frame()) with
open air below it for solder joints, plus a single BACKSTOP wall (open
on the other 3 sides -- see MCU_BACKSTOP_T's comment for why both side
walls that used to exist here were removed, to leave the button and
battery cables' own routing paths clear) so a charging plug pushes
against a floor-anchored wall instead of relying on friction alone. The
battery sits directly on the tray floor (no shelf -- it's a solid cell,
nothing needs clearance beneath it), separated from the MCU only by the
open BATTERY_MCU_GAP air gap (no dividing wall, and so no dedicated
in-plane retention of its own either -- see that constant's comment).
The display has NO posts, shelves, or walls holding it up in the tray at all
-- it's adhesive/tape-mounted directly on top of the battery+MCU row, at
DISPLAY_REST_Z (section 5); nothing in the printed tray registers the
display's position. It additionally gets a full lateral-confinement ring
molded into the LID (screen_lip + screen_wall in build_lid()), open only
on the segment facing the switch column.

SWITCHES: mounted "plate style" -- PCB, a 5mm air gap, then a 14x14mm hole
in the lid's own outer face that the switch upper housing pokes through
and rises above by design (this is how mechanical keyboards work). That
keeps the case a flat, uniform-height prism instead of needing a stepped
top to bury the switch's full housing height.

SNAP FIT: a continuous chamfered bead-in-groove around the tray/lid
perimeter, interrupted only at the USB-C notch, sized and checked against
PLA's real elongation-at-break (read from HARDWARE.md when present) via
snap_fit_strain() (section 6). No separate alignment pins -- the
bead/groove engagement plus the switch plate-hole engagement register the
lid in X/Y between them.

A second, smaller detent grips the display module itself against the
lid's screen retention wall (screen_snap_strain(), section 6) -- the
rigid module plays the "bead" half, the thin cantilevered screen_wall
plays the "groove" half, same physics as the main snap above just
checked separately since its thickness/flex-length differ. It's an
XY-plane (sideways) squeeze, not a Z-axis hook, because the Z room above
the display (STACK_TOP_MARGIN, 0.5mm) is too tight for a cantilever to
ever spring rather than jam -- see "Screen retention" in section 3.

VISIBLE SEAM: sits at the middle of the case height (SEAM_FRACTION=0.5).
The lid has its own full-height "cap wall" above the seam, flush with the
tray's own wall, and a thinner skirt hidden inside the tray's cavity below
the seam purely for the snap engagement.

ASSUMPTIONS: HARDWARE.md gives XY footprints for the display module and
MCU but not their Z thickness, and doesn't specify a switch PCB at all.
Every such figure is a named constant flagged "ASSUMPTION" or "STANDARD,
not from HARDWARE.md" in section 2, and all of them are also listed
together in print_summary() under "Assumed / generic figures" so nothing
is buried.

PLA CAVEAT: PLA's elongation-at-break is roughly 3-5x lower than ABS or
PETG, which matters for a snap fit meant to be opened/closed repeatedly.
snap_fit_strain() targets only ~30% of PLA's ultimate elongation as the
allowable design strain (a fatigue margin, not a one-shot-assembly
margin) -- see SNAP_STRAIN_SAFETY_FRACTION below. If this case will be
opened often, consider printing the lid in PETG instead.
"""

import os
import sys
import math

import FreeCAD as App
import Part
from FreeCAD import Vector

# ====================================================================
# 1. MATERIAL -- read from HARDWARE.md if present, else a flagged default
# ====================================================================

def read_elongation_from_hardware_md(path):
    """Pull the PLA elongation-at-break out of HARDWARE.md's filament
    table. Returns (fraction, source_string). Falls back to a generic
    published PLA figure (and says so) if the file or the row is
    missing."""
    generic_fraction = 0.11  # ~11%, typical published PLA elongation at break
    generic_source = ("GENERIC PLA figure (~11 percent), NOT a datasheet: "
                       "no HARDWARE.md found at '%s'" % path)
    if not os.path.isfile(path):
        return generic_fraction, generic_source
    try:
        with open(path, "r", encoding="utf-8") as f:
            text = f.read()
    except OSError:
        return generic_fraction, generic_source

    for line in text.splitlines():
        if "Elongation at break" in line:
            # table row looks like: | **Elongation at break** | 11.2% |
            cells = [c.strip() for c in line.split("|") if c.strip()]
            for cell in cells:
                if cell.endswith("%"):
                    try:
                        pct = float(cell.rstrip("%"))
                        return pct / 100.0, ("HARDWARE.md filament table: "
                                              "elongation at break = %s" % cell)
                    except ValueError:
                        continue
    return generic_fraction, generic_source


_SCRIPT_DIR = os.path.dirname(os.path.abspath(__file__)) if "__file__" in globals() else os.getcwd()
_HARDWARE_MD = os.path.join(_SCRIPT_DIR, "HARDWARE.md")

ELONGATION_AT_BREAK, ELONGATION_SOURCE = read_elongation_from_hardware_md(_HARDWARE_MD)

# Fraction of ultimate elongation-at-break used as the *allowable design
# strain* for the snap-fit flex. Kept well below 1.0 because: (a) this
# joint is meant to be opened/closed repeatedly, not deformed once, and
# (b) PLA is a fairly brittle thermoplastic with little fatigue margin
# compared to ABS/PETG/nylon (see the module docstring's PLA CAVEAT).
SNAP_STRAIN_SAFETY_FRACTION = 0.30

# ====================================================================
# 2. COMPONENT DIMENSIONS -- HARDWARE.md values where given, flagged
#    assumptions everywhere else
# ====================================================================

# ---- Display: 2.13" SPI E-Ink HAT -----------------------------------
DISPLAY_MODULE_W = 65.0     # HARDWARE.md: full module footprint
DISPLAY_MODULE_D = 30.0     # HARDWARE.md
DISPLAY_ACTIVE_W = 48.55    # HARDWARE.md: active area
DISPLAY_ACTIVE_D = 23.71    # HARDWARE.md
# ASSUMPTION: HARDWARE.md gives no module thickness. 2.13" e-paper HATs
# are typically ~1.2 mm glass + ~1.6 mm PCB + adhesive/spacer, no pin
# header (this device wires to the MCU directly over SPI, not an RPi
# GPIO header) -> budget 4.0 mm. If a populated header is actually used,
# add ~8.5 mm and re-check DISPLAY clearance in print_summary().
DISPLAY_THICKNESS = 4.0

# ---- MCU: Seeed XIAO ESP32-S3 Sense (no camera) ----------------------
MCU_W = 21.0                # HARDWARE.md: board dimensions (long axis)
MCU_D = 17.5                # HARDWARE.md: board dimensions (short axis, USB-C edge)
# ASSUMPTION: XIAO-family boards are ~3.5 mm over the PCB+shield; budget
# 4.0 mm for the assembled board envelope (PCB + antenna/shield + solder).
MCU_THICKNESS = 4.0
# Ordinary solder-joint clearance under the MCU board, sitting on its own
# floor-level shelf (shelf_frame(), build_tray()).
MCU_SHELF_CLEARANCE = 1.0
USB_C_CUTOUT_W = 9.0       # ASSUMPTION: ~10x6mm opening, typical USB-C receptacle
USB_C_CUTOUT_H = 3.0
# ASSUMPTION: connector height above the board's bottom face -- typical
# USB-C receptacle (~3.2mm) sitting on a ~1.2mm PCB. VERIFY against the
# physical board before printing; the cutout has +/-1mm of vertical
# margin built in (see USB_C_CUTOUT_H) to absorb a modest error here.
USB_C_CENTER_Z_ABOVE_SHELF = 3.0

# microSD slot (the Sense expansion board's card reader): a wall opening
# so a card can be slid in/out without opening the case, on the same -Y
# wall as the USB-C port, positioned per the design brief -- 3mm above
# the USB-C notch's own top edge (MICROSD_GAP_ABOVE_USBC, section 5).
# ASSUMPTION: neither the slot's exact board-relative position nor its
# opening size is in HARDWARE.md. Sized for a standard microSD card
# (11 x 1.0mm cross-section, inserted edge-first) plus clearance for the
# card and its holder mechanism -- VERIFY against the physical board
# before printing, same as the USB-C figures above.
MICROSD_SLOT_W = 12.0       # ASSUMPTION: 11mm card width + slide clearance
MICROSD_SLOT_H = 2.0        # ASSUMPTION: ~1mm card thickness + holder/clearance margin
MICROSD_GAP_ABOVE_USBC = 3.0  # per design brief: slot sits 3mm above the USB-C notch's top

# ---- Battery: EEMB 603449 -------------------------------------------
BATTERY_W = 48.0            # measured on the physical cell (overrides HARDWARE.md's 51mm datasheet figure)
BATTERY_D = 34.0            # measured on the physical cell (overrides HARDWARE.md's 34.5mm datasheet figure)
BATTERY_T = 6.3             # HARDWARE.md

# ---- Switches: 2x Cherry MX2A Silent Blue on a hot-swap PCB ----------
SWITCH_HOLE = 14.0           # STANDARD Cherry MX plate-hole spec (14x14mm), also used as the footprint
SWITCH_PITCH = 19.05         # STANDARD keyboard key pitch (0.75in), not in HARDWARE.md
N_SWITCHES = 2
# LID opening per button. Deliberately separate from SWITCH_HOLE (14mm):
# SWITCH_HOLE still drives the PCB footprint/plate spec everywhere else
# in this file, this only enlarges the LID's cutout. At SWITCH_PITCH
# (19.05mm) two adjacent 19mm squares leave only 0.05mm between their
# edges -- see build_lid()'s comment for why that's cut as ONE merged
# rectangle instead of two separate (near-)overlapping boxes.
LID_BUTTON_HOLE = 19.0
# Custom hot-swap PCB: its outline isn't specified anywhere, so this
# margin beyond the switch bodies is sized generously for solder pads /
# socket clearance / routing -- 2.0mm is real, usable margin for a
# hot-swap socket's pads, close to the floor before the PCB itself
# becomes the risk, not the case.
SWITCH_PCB_MARGIN_X = 2.0
SWITCH_PCB_MARGIN_Y = 2.0
SWITCH_PCB_W = SWITCH_PITCH * (N_SWITCHES - 1) + SWITCH_HOLE + 2 * SWITCH_PCB_MARGIN_X
SWITCH_PCB_D = SWITCH_HOLE + 2 * SWITCH_PCB_MARGIN_Y
SWITCH_PCB_THICKNESS = 1.6   # STANDARD FR4 thickness, not in HARDWARE.md
# STANDARD mechanical-keyboard convention, not in HARDWARE.md:
PCB_TO_PLATE = 5.0                    # PCB top surface to underside of plate
SWITCH_HOUSING_ABOVE_PCB = 11.6       # PCB top to top of switch upper housing (informational)
# Clearance needed *below* the switch PCB for the YMDK/Kailh hot-swap
# socket body + the switch's through-PCB plunger pins (typical socket +
# pin protrusion is ~3-3.5mm). The actual value (SWITCH_PCB_BELOW_CLEARANCE)
# is DERIVED in section 5 from the MCU/battery/display stack's own height
# requirement instead, since the stack needs more height than the
# switches themselves do -- see section 5 for the real number.

# ====================================================================
# 3. PRINT / SHELL PARAMETERS
# ====================================================================

WALL_T = 2.0            # general shell wall thickness (floor, ceiling, sides)
CORNER_FILLET_OUTER = 8.0   # external vertical-corner radius -- "fits in the hand"
# Outer TOP/BOTTOM edge treatment: rounds the horizontal rim where the flat
# floor/ceiling face meets the outer wall -- the edges a palm/fingers
# actually rest against, not just the vertical corners. This is a
# SEQUENCE of progressively smaller CHAMFERS (rounded_edge_chamfer(),
# section 7), not a true fillet: a fillet on this rim runs along the same
# tangent-continuous straight+arc loop as CORNER_FILLET_OUTER's own
# rounded corners, and filleting a curved edge like that reliably bulges
# the shape outward at the corners in this OCCT version (confirmed on
# this shape -- the same bug the snap bead's chamfer, below, works around
# the same way). Each stage chamfers the edge the previous stage just
# created, approximating a round as a multi-facet profile rather than one
# flat bevel. Applied early, on the plain outer solid before any other
# feature, so the chamfer geometry stays simple.
# 4 stages is the practical ceiling for this OCCT version: a direct sweep
# against the actual tray/lid shapes shows 5-6 stage sequences at the same
# ~1.95mm total fail outright ("no suitable edges for chamfer or fillet")
# even though 4 stages at that total succeeds. The total (1.9mm) stays a
# comfortable margin under WALL_T/FLOOR_T/CEIL_T (2.0mm).
OUTER_EDGE_CHAMFER_STAGES = [0.7, 0.5, 0.4, 0.3]

# ---- Display window corner/edge treatment (build_lid()) --------------
# Same rounding idea as CORNER_FILLET_OUTER/OUTER_EDGE_CHAMFER_STAGES
# above, applied to the 50x25mm screen opening instead of the whole case
# -- deliberately smaller than both (2.5mm corner vs. 8.0mm; 0.5mm total
# rim bevel vs. 1.9mm), since a window this size would look wrong with
# exterior-scale rounding.
WINDOW_CORNER_R = 2.5
WINDOW_EDGE_CHAMFER_STAGES = [0.3, 0.2]

FIT_CLEARANCE_XY = 0.30     # per-side clearance around dropped-in components
FIT_CLEARANCE_Z = 0.50      # vertical clearance above components

ROW_GAP = 2.0            # gap between component zones (rib/wire-routing space)
BORDER = 2.0             # gap between innermost wall face and component zones

# ---- MCU retention -----------------------------------------------------
# The MCU's own shelf_frame (section 8) gives it somewhere to rest with
# under-board clearance, but a plain flat ledge provides NO in-plane
# retention at all -- friction only. That's a real problem specifically
# for this board: charging means repeatedly pushing a USB-C plug in
# through the case wall, a genuine horizontal shove aimed straight at
# the board. A single BACKSTOP wall (open on all 3 other sides) turns
# that push into compression against a wall anchored in the floor,
# instead of relying on friction to hold the board still. Uses a TIGHTER
# clearance than the general FIT_CLEARANCE_XY (0.30mm) specifically here
# -- the board still needs to drop in from above without binding, but the
# whole point is minimizing the slop it can shift through before the
# push force is actually caught.
#
# NO SIDE WALLS at all (both used to exist, both removed by request): the
# switch-column side blocked the button cables' own routing path through
# ROW_GAP, and the battery side blocked routing/assembly across
# BATTERY_MCU_GAP once that dividing wall came out too -- see
# BATTERY_MCU_GAP's own comment. The backstop alone is still enough to
# catch a USB-C push (the push is front-to-back, along Y); the side
# walls only ever stopped off-axis rocking, not the main insertion force.
MCU_RETENTION_CLEARANCE = 0.15
MCU_BACKSTOP_T = 2.0        # back wall thickness -- takes the insertion push

# ---- Battery / MCU gap (no dividing wall) -------------------------------
# The battery and MCU used to share a single dividing wall here (both the
# battery's own in-plane retention AND the MCU zone's -X boundary), with a
# cable notch cut through it for the battery's power leads. Removed
# entirely per request -- it was blocking easy cable routing between the
# two zones, the same complaint that got the MCU's switch-side wall
# removed above. BATTERY_MCU_GAP is now just open floor, no printed
# material: enough of an air gap for the battery's leads to cross to the
# MCU without any notch, and to keep the two components from touching
# directly at nominal size.
#
# TRADE-OFF: the battery now has NO dedicated in-plane retention at all
# (previously this wall was its only one -- see the removed comment's own
# reasoning). Nothing stops it sliding toward the MCU besides friction
# and the tape called out in print_summary()'s checklist; if that's not
# enough in practice, the fix is a small standalone retention nub/rail
# added back on the battery's own side only (not spanning to the MCU).
BATTERY_MCU_GAP = 1.0

# ---- Screen retention -------------------------------------------------
# No lid-side snap TAB hanging from the ceiling: the only Z room
# available for a tab to hang from the ceiling and flex is
# STACK_TOP_MARGIN (0.5mm), and a beam that short is thousands of times
# stiffer than the case's own 5.5mm snap skirt (deflection ~ 1/L^3) --
# it would jam or not touch, never spring.
#
# The display has no posts, shelves, or walls in the TRAY at all (see the
# module docstring's SUPPORT note) -- it's adhesive/tape-mounted directly
# on top of the battery+MCU row. Its only retention is on the LID side:
# screen_lip and screen_wall (build_lid()) form a ring around its
# perimeter, open only on the segment facing the switch column.
#
# The physical module measured ~1mm longer along its 65mm (W) axis than
# the plain FIT_CLEARANCE_XY (0.30mm/side) pocket allowed for -- too
# tight to seat. SCREEN_LENGTH_EXTRA_CLEARANCE below adds that 1mm
# entirely on the FAR (+X) side of the pocket, not split evenly: the
# NEAR (-X) side is flush against the case's own exterior wall (only
# ~0.3mm of slack before hitting solid material there -- see lip_x0 in
# build_lid()), so all the growth has to happen on the +X side, which has
# several mm of open cavity to spare before the switch column.
SCREEN_LENGTH_EXTRA_CLEARANCE = 1.0  # added to lip_w's W-axis (65mm) span only, +X side

# ---- Screen snap-fit detent -------------------------------------------
# On top of the plain clearance-fit lip/wall above, add real assembly
# resistance: a small inward bead on screen_wall's two LONG sides only
# (the -Y and +Y segments, each spanning the module's full W-axis
# length) -- the module's rigid top-outer edge cams these chamfered
# beads outward as the lid is lowered into place, then the wall's own
# elastic spring-back squeezes the module's sides once seated. Deliberately
# NOT on the -X segment (already fused solid into the exterior wall, with
# only ~0.3mm of clearance to flex into -- too tight and not a free
# cantilever anyway) or the +X segment (already interrupted by
# SCREEN_WALL_BUTTON_NOTCH_W). Both long sides have >5mm of open cavity
# beyond them before the next exterior wall (see build_lid()), plenty of
# room to flex into. Checked separately from the main snap
# (screen_snap_strain(), section 6) since screen_wall's thickness
# (SCREEN_WALL_T) and cantilever length (SCREEN_RETENTION_WALL_H, section
# 5) both differ from the main snap's skirt. Deliberately NOT chamfered
# like the main bead/groove -- see the detent's own comment in
# build_lid() for why a lead-in ramp isn't worth it at this scale.
SCREEN_SNAP_INTERFERENCE = 0.15  # d -- see screen_snap_strain() for margin
SCREEN_SNAP_BAND_H = 1.0         # height of the detent band along the wall
SCREEN_SNAP_TIP_OFFSET = 0.3     # how far above screen_wall's own free tip the detent sits (BEAD_TIP_OFFSET's analog)
SCREEN_SNAP_OVERLAP_EPS = 0.1    # guaranteed-fuse overlap into the wall, same idea as OVERLAP_EPS elsewhere
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

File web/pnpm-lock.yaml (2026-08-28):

lockfileVersion: '9.0'

settings:
  autoInstallPeers: true
  excludeLinksFromLockfile: false

importers:

  .:
    dependencies:
      '@lucide/svelte':
        specifier: ^1.34.0
        version: 1.34.0(svelte@5.56.9)
    devDependencies:
      '@sveltejs/adapter-static':
        specifier: ^3.0.10
        version: 3.0.10(@sveltejs/kit@2.70.2(@sveltejs/vite-plugin-svelte@7.3.0(svelte@5.56.9)(vite@8.2.1(@types/node@24.13.3)))(svelte@5.56.9)(typescript@6.0.3)(vite@8.2.1(@types/node@24.13.3)))
      '@sveltejs/kit':
        specifier: ^2.63.0
        version: 2.70.2(@sveltejs/vite-plugin-svelte@7.3.0(svelte@5.56.9)(vite@8.2.1(@types/node@24.13.3)))(svelte@5.56.9)(typescript@6.0.3)(vite@8.2.1(@types/node@24.13.3))
      '@sveltejs/vite-plugin-svelte':
        specifier: ^7.1.2
        version: 7.3.0(svelte@5.56.9)(vite@8.2.1(@types/node@24.13.3))
      '@types/node':
        specifier: ^24.0.0
        version: 24.13.3
      svelte:
        specifier: ^5.56.1
        version: 5.56.9
      svelte-check:
        specifier: ^4.6.0
        version: 4.7.6(picomatch@4.0.5)(svelte@5.56.9)(typescript@6.0.3)
      typescript:
        specifier: ^6.0.3
        version: 6.0.3
      vite:
        specifier: ^8.0.16
        version: 8.2.1(@types/node@24.13.3)

packages:

  '@jridgewell/gen-mapping@0.3.13':
    resolution: {integrity: sha512-2kkt/7niJ6MgEPxF0bYdQ6etZaA+fQvDcLKckhy1yIQOzaoKjBBjSj63/aLVjYE3qhRt5dvM+uUyfCg6UKCBbA==}

  '@jridgewell/remapping@2.3.5':
    resolution: {integrity: sha512-LI9u/+laYG4Ds1TDKSJW2YPrIlcVYOwi2fUC6xB43lueCjgxV4lffOCZCtYFiH6TNOX+tQKXx97T4IKHbhyHEQ==}

  '@jridgewell/resolve-uri@3.1.2':
    resolution: {integrity: sha512-bRISgCIjP20/tbWSPWMEi54QVPRZExkuD9lJL+UIxUKtwVJA8wW1Trb1jMs1RFXo1CBTNZ/5hpC9QvmKWdopKw==}
    engines: {node: '>=6.0.0'}

  '@jridgewell/sourcemap-codec@1.5.5':
    resolution: {integrity: sha512-cYQ9310grqxueWbl+WuIUIaiUaDcj7WOq5fVhEljNVgRfOUhY9fy2zTvfoqWsnebh8Sl70VScFbICvJnLKB0Og==}

  '@jridgewell/trace-mapping@0.3.31':
    resolution: {integrity: sha512-zzNR+SdQSDJzc8joaeP8QQoCQr8NuYx2dIIytl1QeBEZHJ9uW6hebsrYgbz8hJwUQao3TWCMtmfV8Nu1twOLAw==}

  '@lucide/svelte@1.34.0':
    resolution: {integrity: sha512-sHFL8KVSaPXv0dsmdUTq4q/tj8clT2XYejnoSg0mHObpXWn/9SfET4f14v/7VOba1IsbPIW9+sWaq+Qq1wTdNA==}
    peerDependencies:
      svelte: ^5

  '@oxc-project/types@0.144.0':
    resolution: {integrity: sha512-nuhZIOLuI6TFQ32I/WnUx+SCPY7SdSKwgnFHydAuoS1+Z4BRcaP+RRJmGzl9lw+0OFF7UmaESf7KQRXaNLHypg==}

  '@polka/url@1.0.0-next.29':
    resolution: {integrity: sha512-wwQAWhWSuHaag8c4q/KN/vCoeOJYshAIvMQwD4GpSb3OiZklFfvAgmj0VCBBImRpuF/aFgIRzllXlVX93Jevww==}

  '@rolldown/binding-android-arm64@1.2.4':
    resolution: {integrity: sha512-jHC2cnyKz5xU2fhECtFl8OZ83cYNt13GZQD+0uMJ/X3o+ijmd56okHhTUwxVSHPx1IRVIJEZ1/1pPzeLCU6XKA==}
    engines: {node: ^20.19.0 || >=22.12.0}
    cpu: [arm64]
    os: [android]

  '@rolldown/binding-darwin-arm64@1.2.4':
    resolution: {integrity: sha512-Dc5mPD8F5F/FS8i01syd7FTF6yB2fVthH/TRkjwJkzUK6EpoxHtqvZQP5Zwq80/5z19TWYHIg1KOHboCgVx/aQ==}
    engines: {node: ^20.19.0 || >=22.12.0}
    cpu: [arm64]
    os: [darwin]

  '@rolldown/binding-darwin-x64@1.2.4':
    resolution: {integrity: sha512-fpDm4oBo6SqLvWUYCmFhdde3U9KH2fRNNMeAnAPAIwxRL345xutL0EtEUcuoxsoazdJGv/MuDBQHlCDrtbvqOg==}
    engines: {node: ^20.19.0 || >=22.12.0}
    cpu: [x64]
    os: [darwin]

  '@rolldown/binding-freebsd-x64@1.2.4':
    resolution: {integrity: sha512-rSJoreDE/HoIzoaib6MTp5jQtCTdMHKIvItAKT/ImS6Y6Ww76oUaeMyp4Vc/fAgd/ehji068IxetHXAnqUwN9A==}
    engines: {node: ^20.19.0 || >=22.12.0}
    cpu: [x64]
    os: [freebsd]

  '@rolldown/binding-linux-arm-gnueabihf@1.2.4':
    resolution: {integrity: sha512-/jm8OGHgn7oGaJu3i/qZI9spUGcJ+y/lk43ttQ/iO1tOd9NissG6o97bighBCiL+BKRngmcDuR6ikfwYdJmVuQ==}
    engines: {node: ^20.19.0 || >=22.12.0}
    cpu: [arm]
    os: [linux]

  '@rolldown/binding-linux-arm64-gnu@1.2.4':
    resolution: {integrity: sha512-tIP06BeD9EqvECBrPZ+sqdPlYrT+aYaAiu1wYziVx5elRK/ftm33JxVDy2bXGbr6J0CrtirCkR87/X5a2euEng==}
    engines: {node: ^20.19.0 || >=22.12.0}
    cpu: [arm64]
    os: [linux]
    libc: [glibc]

  '@rolldown/binding-linux-arm64-musl@1.2.4':
    resolution: {integrity: sha512-Ql1Q0EQqVThvn9VAVlwNzsUvbSFtCMGjLpRRi4pk5i7NZZ4n5ISiLMjHYtus4VQ2PvkSw24zyaCVsiS+sXPj1w==}
    engines: {node: ^20.19.0 || >=22.12.0}
    cpu: [arm64]
    os: [linux]
    libc: [musl]

  '@rolldown/binding-linux-ppc64-gnu@1.2.4':
    resolution: {integrity: sha512-GjbjXD4XXfN19D0LZNbmiCBUoDiRACsYHr0yaIbbn8aFsXjHZifcYqu/W5Er5X2X990WjHXFrxarn5chzItorQ==}
    engines: {node: ^20.19.0 || >=22.12.0}
    cpu: [ppc64]
    os: [linux]
    libc: [glibc]

  '@rolldown/binding-linux-s390x-gnu@1.2.4':
    resolution: {integrity: sha512-p5WR0NOwaRmJ/B1b6IjEFLLivwEsf3PrdBIhRbhTCQisbo2SvHHpG4ELB/+FgQNnB88LTOF86upmJmbvZdQ2lw==}
    engines: {node: ^20.19.0 || >=22.12.0}
    cpu: [s390x]
    os: [linux]
    libc: [glibc]
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

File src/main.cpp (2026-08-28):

// inkbridge — Home Assistant e-ink remote (XIAO ESP32-S3 + Waveshare 2.13" V4)
//
// Architecture follows CrossPoint Reader: HAL singletons (display, gpio),
// Activity/ActivityManager screen stack, SETTINGS persistence singleton.
// Boot goes straight to the menu; no radio is started until the user asks.

#include <Arduino.h>
#include <HalDisplay.h>
#include <HalGPIO.h>
#include <esp_sleep.h>

#include "IdleSleep.h"
#include "InkBridgeSettings.h"
#include "Version.h"
#include "activities/ActivityManager.h"
#include "activities/menu/MainMenuActivity.h"
#include "components/UITheme.h"
#include "network/ConfigWebServer.h"

HalDisplay display;
HalGPIO gpio;
ActivityManager activityManager;

namespace {
// Sleep (idle-timeout) is allowed on any screen except while the config web
// server is running (ConfigWebServer::anyRunning — set by whichever screen
// started it, AP setup or a connected Wi-Fi session) — never nap out from
// under someone actively using the web UI. Neither button GPIO is RTC-
// capable, so true deep sleep (ext0/ext1 wakeup) isn't available on this
// wiring; light sleep's GPIO wakeup works on any digital pin and still
// preserves all state, so waking just resumes loop() normally.

// The header's status icons (moon/lightning bolt) only reflect current
// state when something else triggers a redraw — a button press, or a
// screen change. Left alone, an icon would go stale the moment the USB
// cable is (un)plugged in the background, or once the idle timer crosses
// into its pre-sleep warning window with nothing pressed in the meantime.
// Poll both for a change and, if seen, refresh just that corner — cheap to
// check every loop(), and only touches the display on an actual transition.
bool lastUsbPlugged = false;
bool lastNearSleep = false;

void enterLightSleep() {
  Serial.println("[Main] idle — light sleep until a button is pressed");
  Serial.flush();
  gpio.prepareForSleep();
  esp_light_sleep_start();
  gpio.begin();       // sleep's GPIO wakeup config overwrote the FALLING-edge ISR setup
  gpio.resetState();  // discard the waking press itself — see HalGPIO::resetState()
  Serial.println("[Main] woke up");
}

void drawSplash() {
  auto& g = display.gfx();
  auto& t = display.text();
  g.fillScreen(GxEPD_WHITE);
  t.setFont(UITheme::FONT_TITLE);
  t.setForegroundColor(GxEPD_BLACK);
  int w = t.getUTF8Width("inkbridge");
  t.setCursor((g.width() - w) / 2, 60);
  t.print("inkbridge");
  t.setFont(UITheme::FONT_SMALL);
  String version = String("v") + INKBRIDGE_VERSION;
  w = t.getUTF8Width(version.c_str());
  t.setCursor((g.width() - w) / 2, 78);
  t.print(version);
}
}  // namespace

void setup() {
  Serial.begin(115200);

  gpio.begin();
  display.begin();
  SETTINGS.load();
  UITheme::applyFontFamily(SETTINGS.fontFamily);

  display.refresh(drawSplash, HalDisplay::FULL_REFRESH);

  activityManager.replaceActivity(std::make_unique<MainMenuActivity>());
  IdleSleep::noteActivity();
  lastUsbPlugged = Serial.isPlugged();
  Serial.println("[Main] inkbridge ready");
}

void loop() {
  gpio.update();
  if (gpio.anyEventThisFrame()) IdleSleep::noteActivity();
  activityManager.loop();

  Activity* current = activityManager.getCurrentActivity();
  bool sleepEligible = !ConfigWebServer::anyRunning();

  // Mirrors the same condition UiChrome::drawHeader() computes internally,
  // just to know when the icon needs a proactive redraw (see below).
  bool usbPlugged = Serial.isPlugged();
  bool nearSleep = sleepEligible && IdleSleep::nearTimeout();
  if (current && (usbPlugged != lastUsbPlugged || nearSleep != lastNearSleep)) {
    lastUsbPlugged = usbPlugged;
    lastNearSleep = nearSleep;
    display.refreshRegion(display.width() - 20, 0, 20, UITheme::HEADER_H,
                           [current] { current->render(); });
  }

  if (sleepEligible && IdleSleep::timedOut()) {
    enterLightSleep();
    IdleSleep::noteActivity();
  }

  delay(10);
}

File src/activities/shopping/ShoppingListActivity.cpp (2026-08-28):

#include "ShoppingListActivity.h"

#include <HalGPIO.h>
#include <WiFi.h>

#include <algorithm>

#include "../../components/Icons.h"
#include "../../components/UiChrome.h"
#include "../../components/UITheme.h"
#include "../../i18n/I18n.h"
#include "../ActivityManager.h"

void ShoppingListActivity::onEnter() {
  Activity::onEnter();
  items = SETTINGS.shoppingList();
  sortItems();
  pushQueue.clear();
  pushIndex = 0;
  syncOk = false;
  selected = 0;
  scrollOffset = 0;

  if (!SETTINGS.haShoppingListEntity.length()) {
    state = SyncState::DONE;
    return;
  }

  connector.begin();
  state = connector.status() == WifiConnector::Status::NO_NETWORKS ? SyncState::DONE
                                                                    : SyncState::CONNECTING;
}

void ShoppingListActivity::onExit() {
  WiFi.disconnect(true);
  WiFi.mode(WIFI_OFF);
  Activity::onExit();
}

void ShoppingListActivity::onBack() { activityManager.popActivity(); }

void ShoppingListActivity::loop() {
  if (gpio.wasLongPressed(HalGPIO::BTN_B)) {
    onBack();
    return;
  }

  if (state == SyncState::DONE) {
    UiListActivity::loop();
    return;
  }
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

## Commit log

2026-08-26 change: locker and usbc fixed
    [case_assembled_preview.stl, case_bottom.stl, case_preview.FCStd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]
2026-08-26 change: fix button section
    [case_assembled_preview.stl, case_bottom.stl, case_preview.FCStd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]
2026-08-27 change: remove 3d pilars
    [case_assembled_preview.stl, case_bottom.stl, case_preview.FCStd]
2026-08-27 change: add micro ssd
    [case_assembled_preview.stl, case_bottom.stl, case_preview.FCStd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]
2026-08-27 change: screen holder
    [case_assembled_preview.stl, case_preview.FCStd, case_top.stl]
2026-08-27 change minor config of the bottom case
    [case_assembled_preview.stl, case_bottom.stl, case_preview.FCStd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]
2026-08-27 change: final case iteration
    [case_assembled_preview.stl, case_bottom.stl, case_preview.FCStd]
2026-08-28 fix: awake button refresh
    [main.cpp]
2026-10-22 fix: case
